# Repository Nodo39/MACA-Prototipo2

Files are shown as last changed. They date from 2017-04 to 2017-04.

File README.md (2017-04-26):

# MACA-Prototipo2

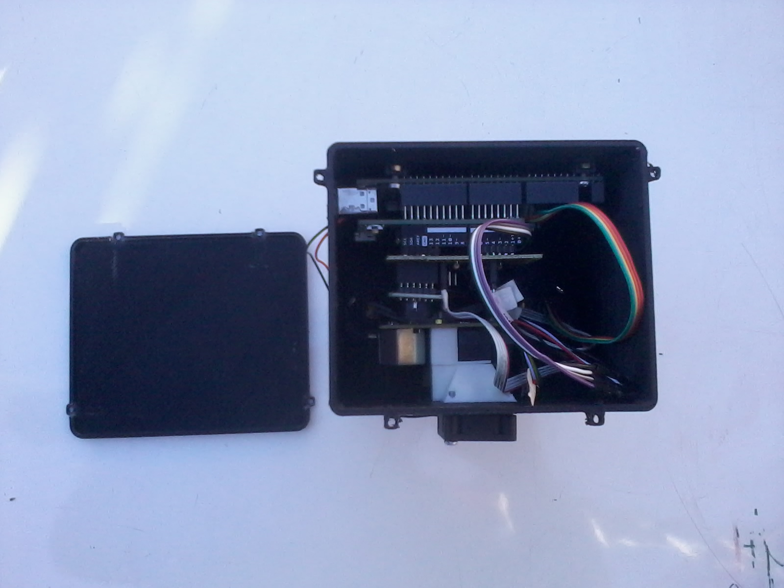
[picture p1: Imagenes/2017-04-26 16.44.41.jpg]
Vista superior

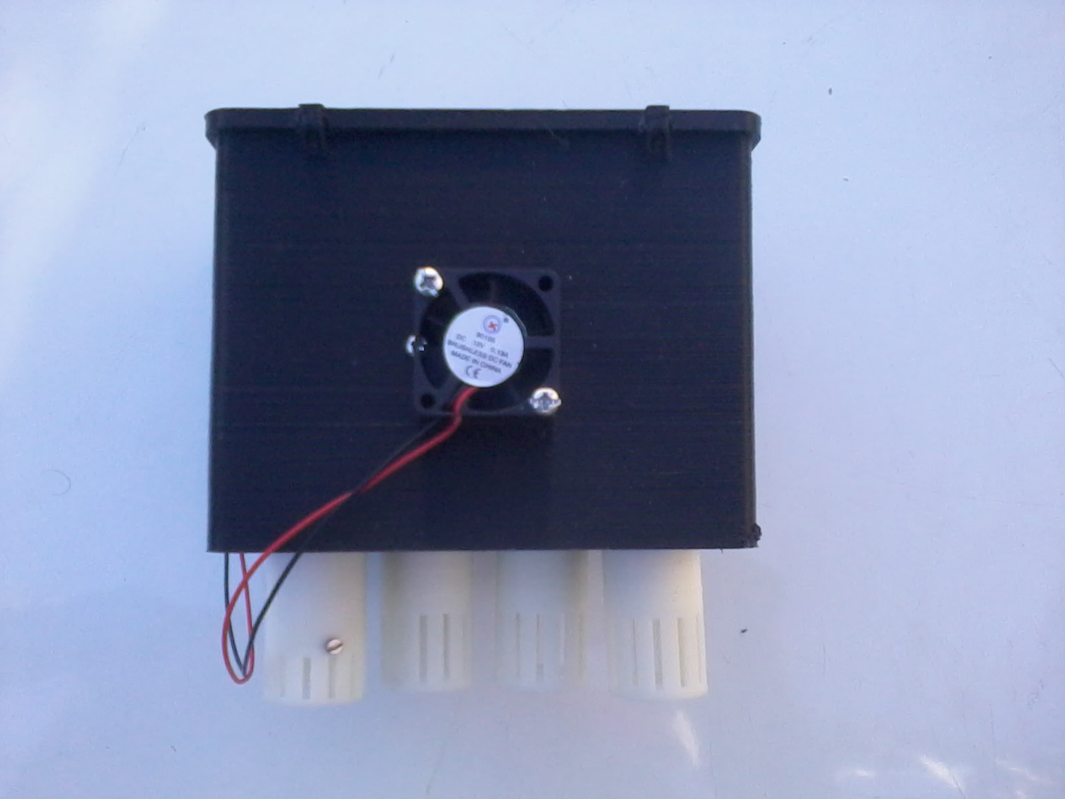
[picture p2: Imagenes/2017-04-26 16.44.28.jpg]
Vista frontal


MACA-Prototipo2 es una pequeña estación de monitoreo de la calidad del aire abierta y de bajo costo que combina un detector óptico de partìculas y sensores de oxidos metálicos (MICS-e2v) para los gases CO, NO2 and O3.
Esta estacíon es un remix y una adaptación de monitores abiertos previos (AQ Egg, Smartcitizen, Dustduino and Airbeam).
El prototipo está basado en un Arduino Mega 2560 y un shield WiFi.
En este repositorio estamos documentando el hardware y el sofware del equipo.
Para mayor información sobre el proyecto se puede consultar la wiki www.monitorabierto.wikidot.com o la [nota de investigaciòn en Public Lab](https://publiclab.org/notes/nanocastro/04-26-2017/maca-open-air-quality-monitor-project-in-latin-america)

MACA-Prototipo2 is an open, small and low cost air quality monitoring station that combines an optical particle detector (Shinyei) and metal oxide gas sensors for CO, NO2 and O3 (MICS-e2v).  
It’s a remix and adaptation of previous citizen air quality monitors (AQ Egg, Smartcitizen, Dustduino and Airbeam). 
This prototype is based on an Arduino Mega 2560 and a WiFi Shield.
In this respository we are documenting the hardware and software of this device.
For further information about the project you can check the wiki www.monitorabierto.wikidot.com or the [Research Note at Public Lab](https://publiclab.org/notes/nanocastro/04-26-2017/maca-open-air-quality-monitor-project-in-latin-america)

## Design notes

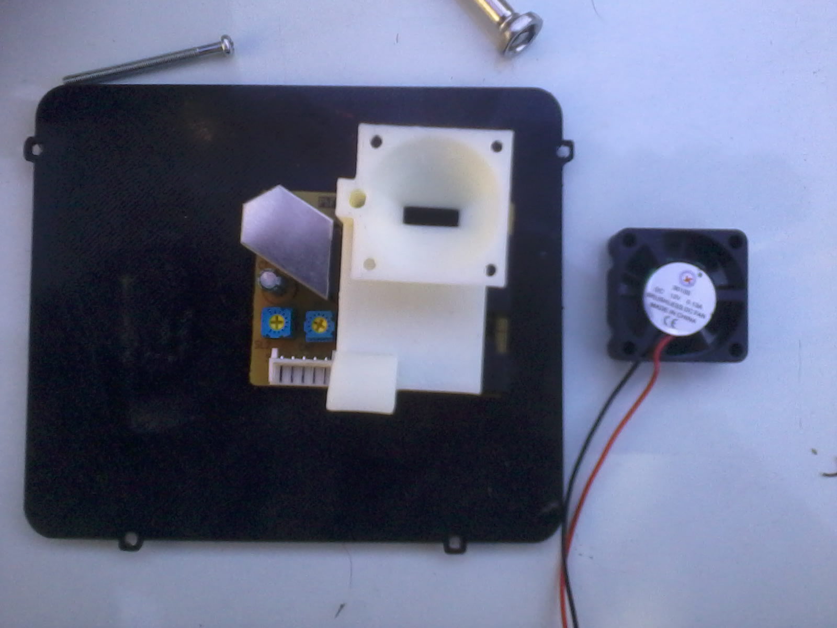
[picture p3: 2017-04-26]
Imagenes/2017-04-26 16.49.09.jpg

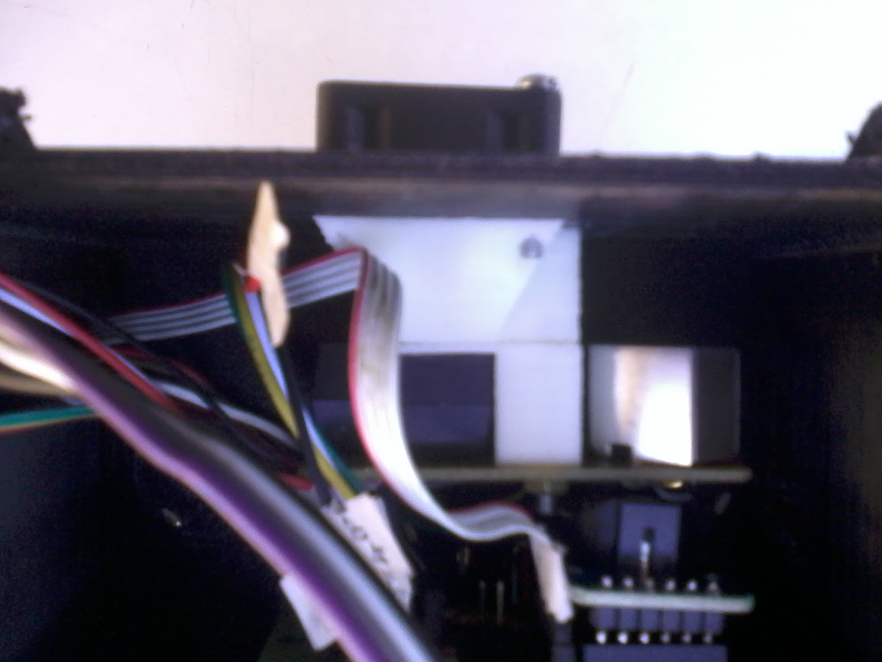
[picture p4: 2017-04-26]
Imagenes/2017-04-26 16.45.03.jpg

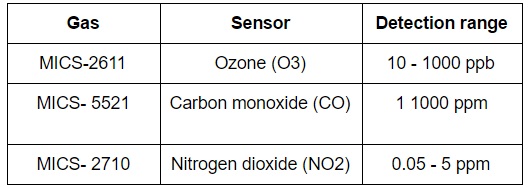
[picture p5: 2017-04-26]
Imagenes/gas sensors.jpg

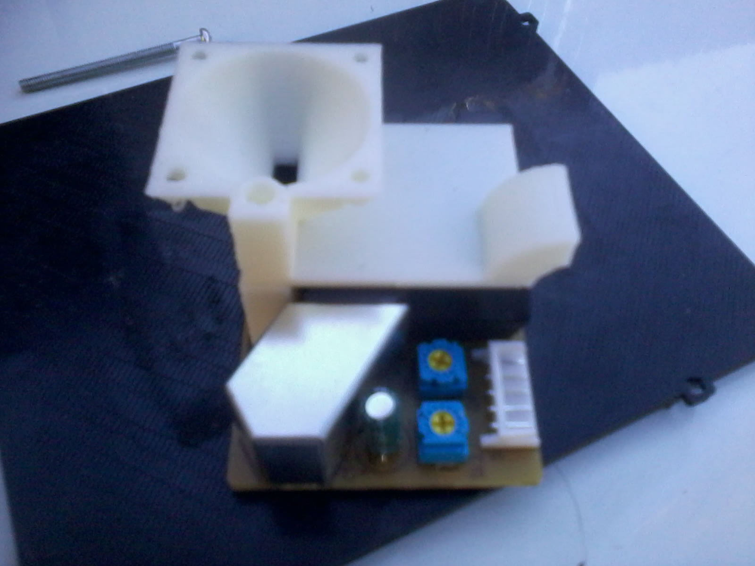
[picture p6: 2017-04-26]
Imagenes/2017-04-26 16.49.48.jpg

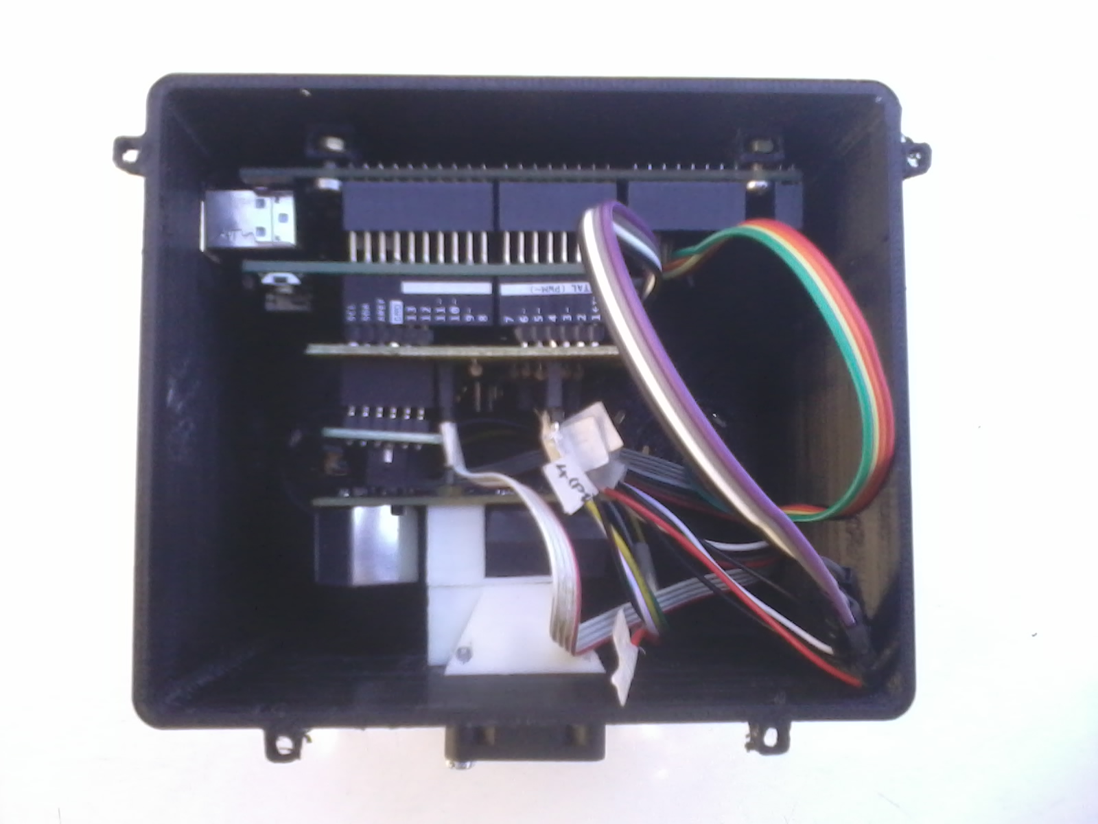
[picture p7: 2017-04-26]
Imagenes/2017-04-26 16.39.17.jpg

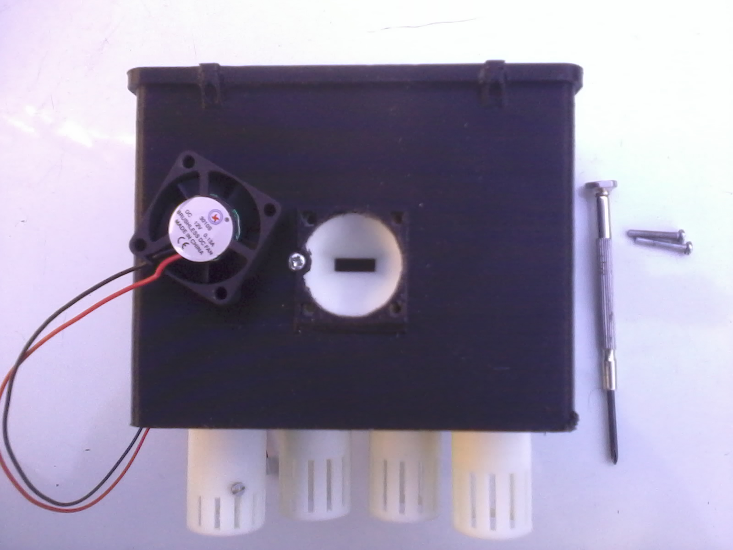
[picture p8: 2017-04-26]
Imagenes/2017-04-26 16.47.10.jpg

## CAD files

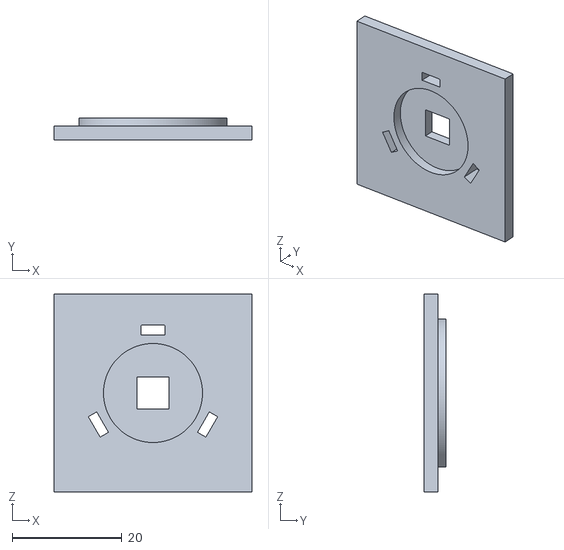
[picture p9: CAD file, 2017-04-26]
Hardware/Carcaza/acople base.stl
36.0 x 4.00 x 36.0

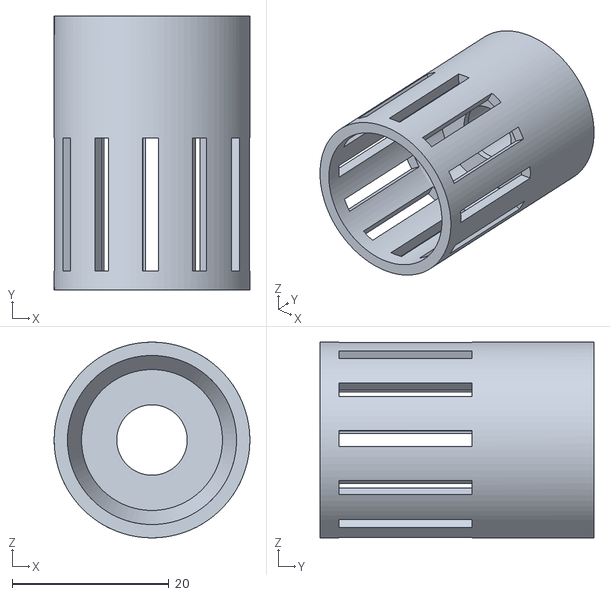
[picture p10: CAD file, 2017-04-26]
Hardware/Carcaza/Nueva carpeta/MICS holder v3.stl
25.0 x 35.0 x 25.0

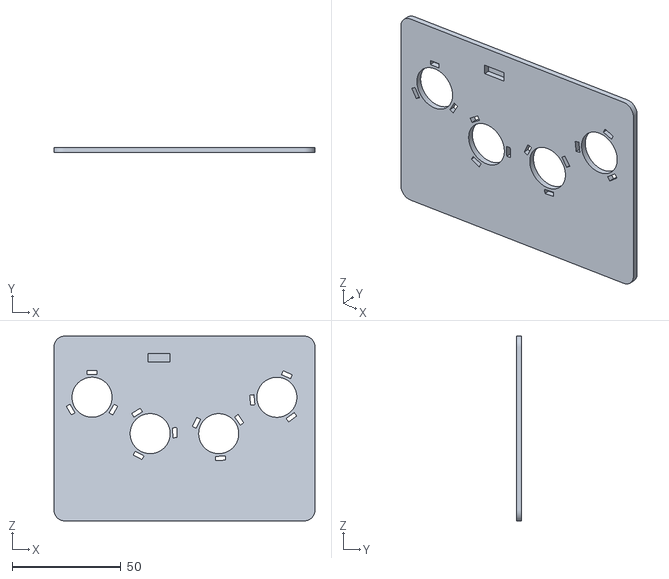
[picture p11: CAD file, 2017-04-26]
Hardware/Carcaza/Body2.stl
120.0 x 2.50 x 85.0

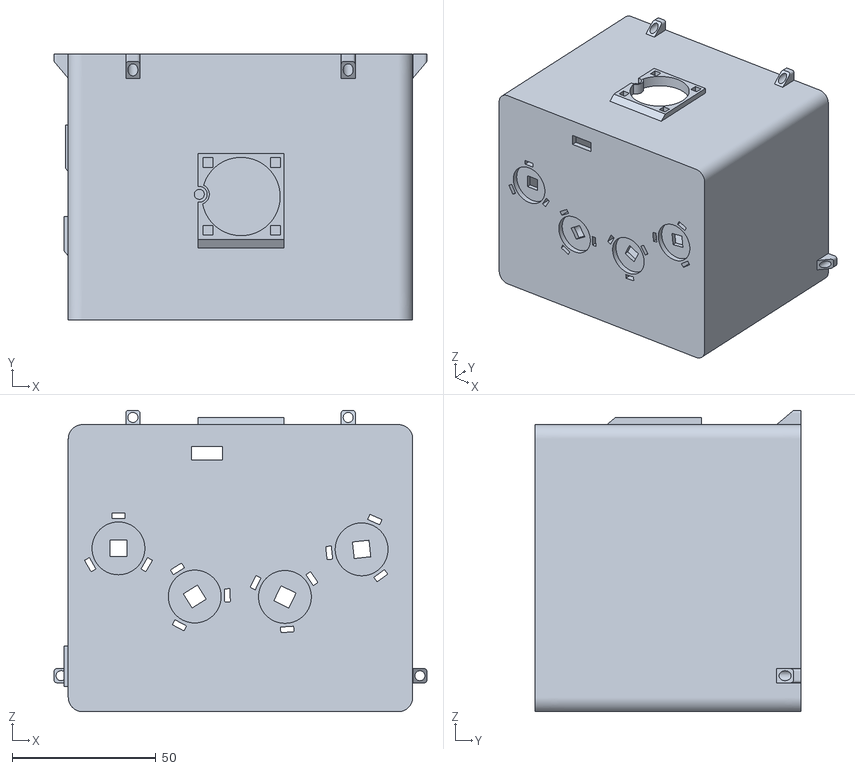
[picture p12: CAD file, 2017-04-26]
Hardware/Carcaza/Nueva carpeta/carcaza maca2 v1.stl
129.9 x 92.5 x 105.0

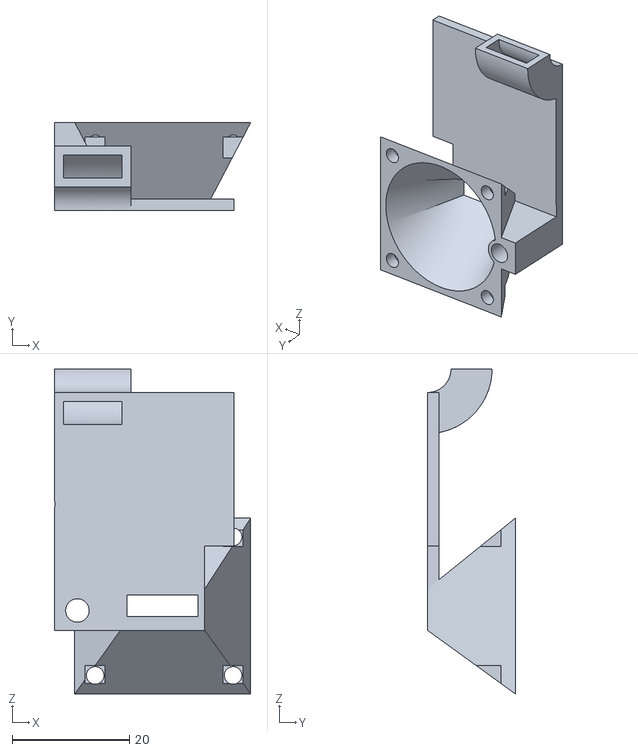
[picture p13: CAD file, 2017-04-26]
Hardware/Carcaza/Nueva carpeta/shinyei.stl
33.5 x 15.0 x 55.4

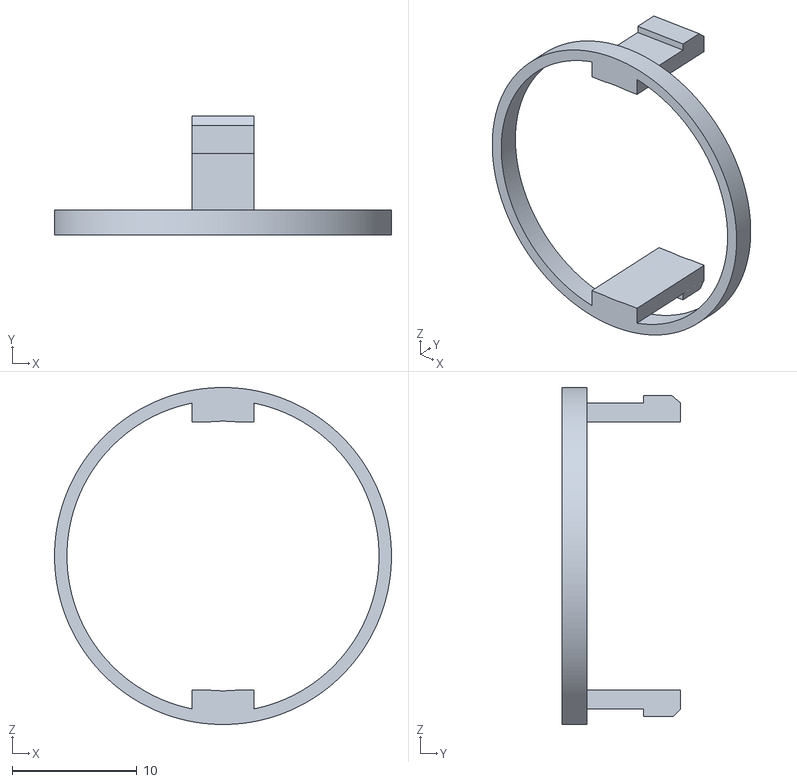
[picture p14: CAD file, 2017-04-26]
Hardware/Carcaza/ganchos sensor.stl
27.0 x 9.51 x 27.0

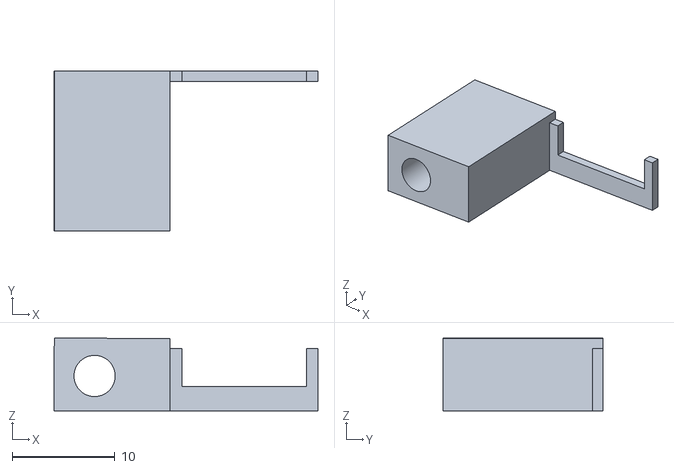
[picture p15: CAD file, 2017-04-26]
Hardware/Carcaza/Nueva carpeta/taco shinyei.stl
25.6 x 15.5 x 7.06

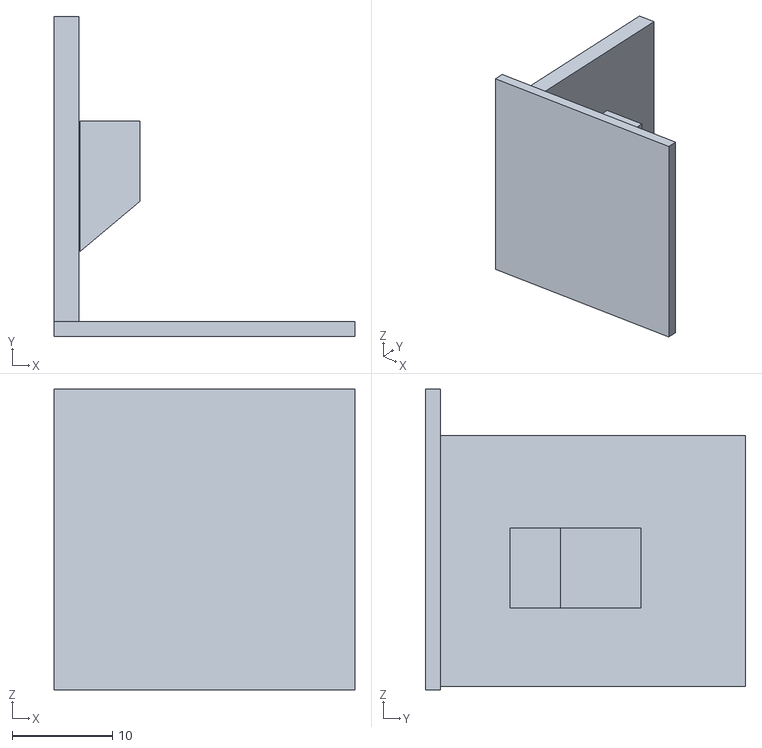
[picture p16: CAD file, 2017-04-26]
Hardware/Carcaza/anclaje pared.stl
30.0 x 31.9 x 30.0

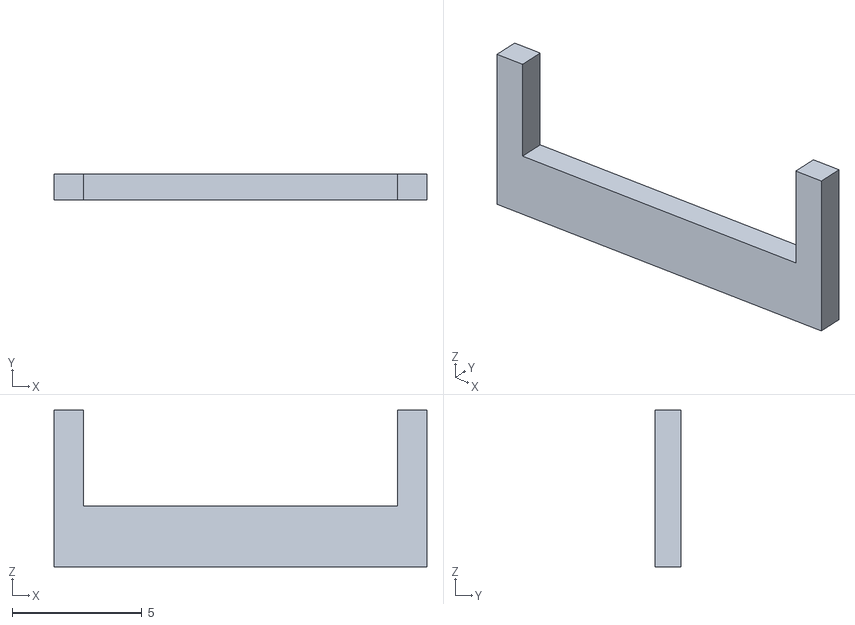
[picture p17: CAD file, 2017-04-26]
Hardware/Carcaza/Nueva carpeta/bordecito.stl
14.4 x 1.00 x 6.04

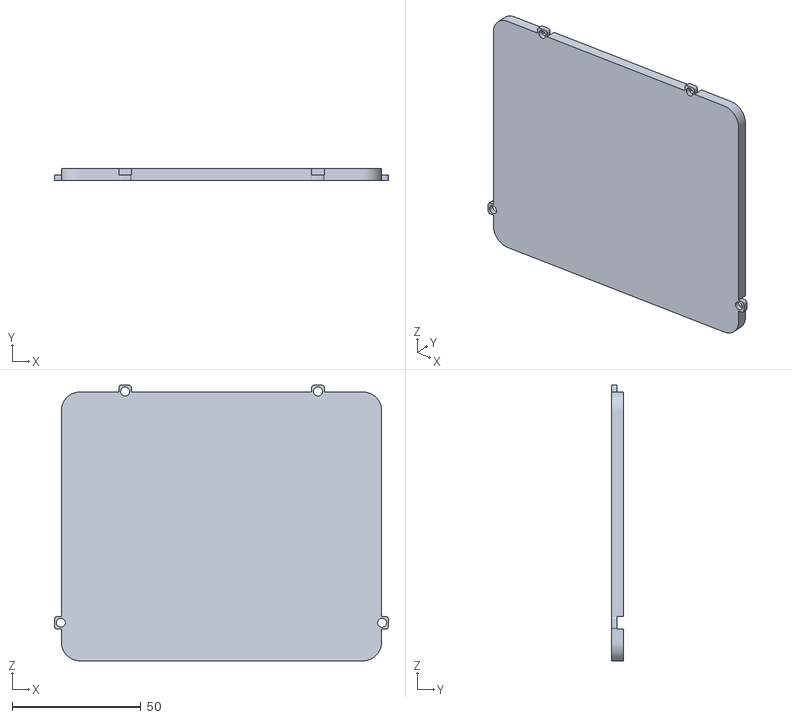
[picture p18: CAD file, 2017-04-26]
Hardware/Carcaza/Nueva carpeta/tapa.stl
129.9 x 4.50 x 107.3

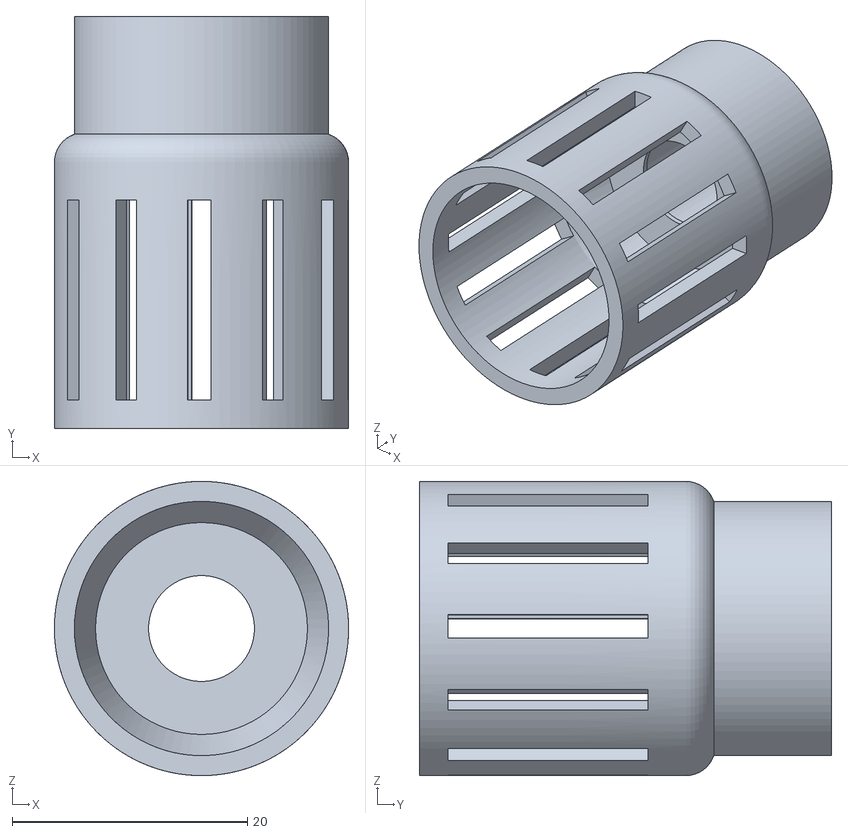
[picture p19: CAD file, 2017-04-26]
Hardware/Carcaza/sensor holder.stl
25.0 x 35.0 x 25.0

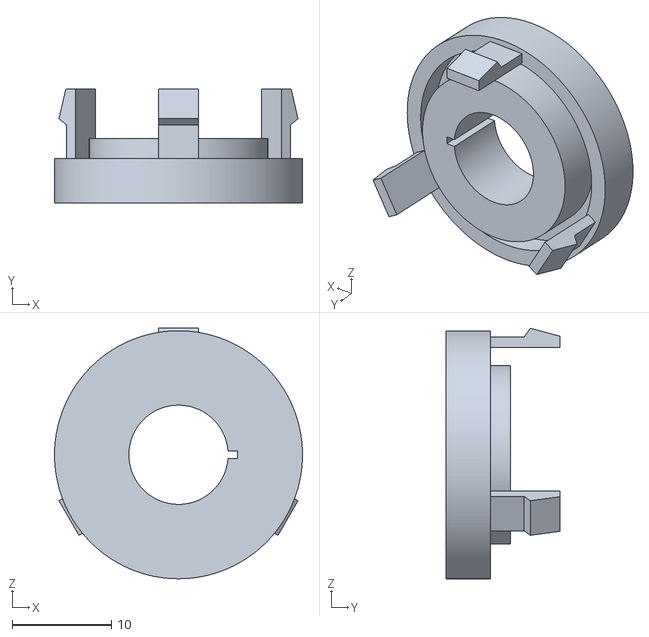
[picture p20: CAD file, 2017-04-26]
Hardware/Carcaza/gancho sensores.stl
25.0 x 11.5 x 25.3

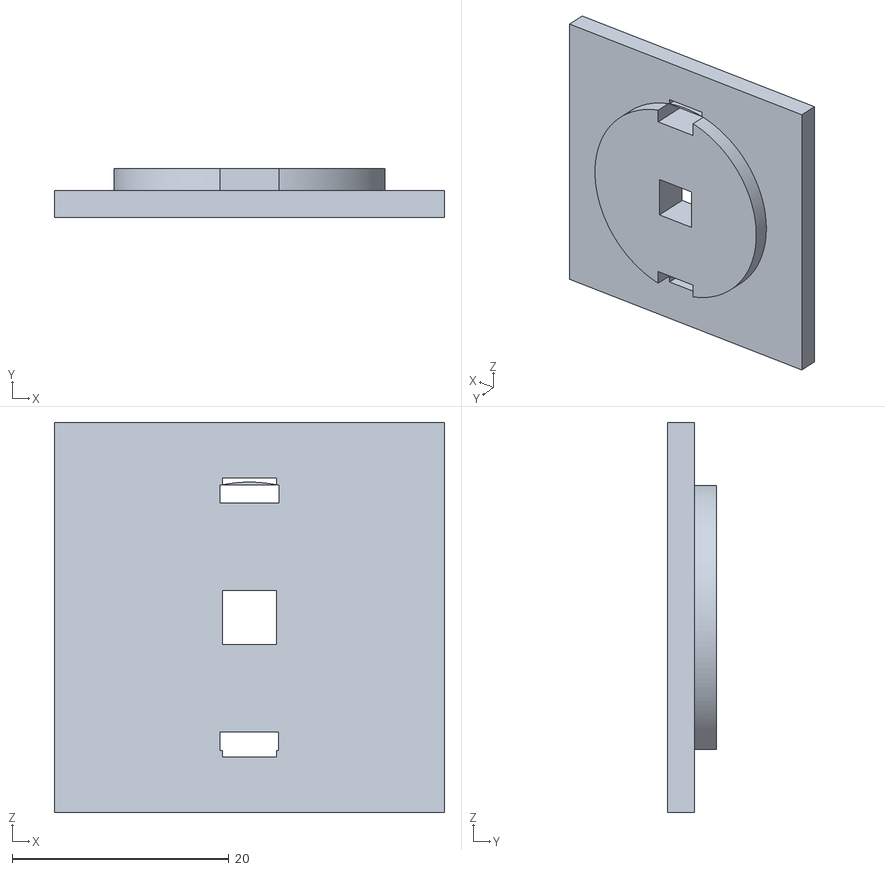
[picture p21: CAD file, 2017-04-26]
Hardware/Carcaza/union carcaza.stl
36.0 x 4.50 x 36.0

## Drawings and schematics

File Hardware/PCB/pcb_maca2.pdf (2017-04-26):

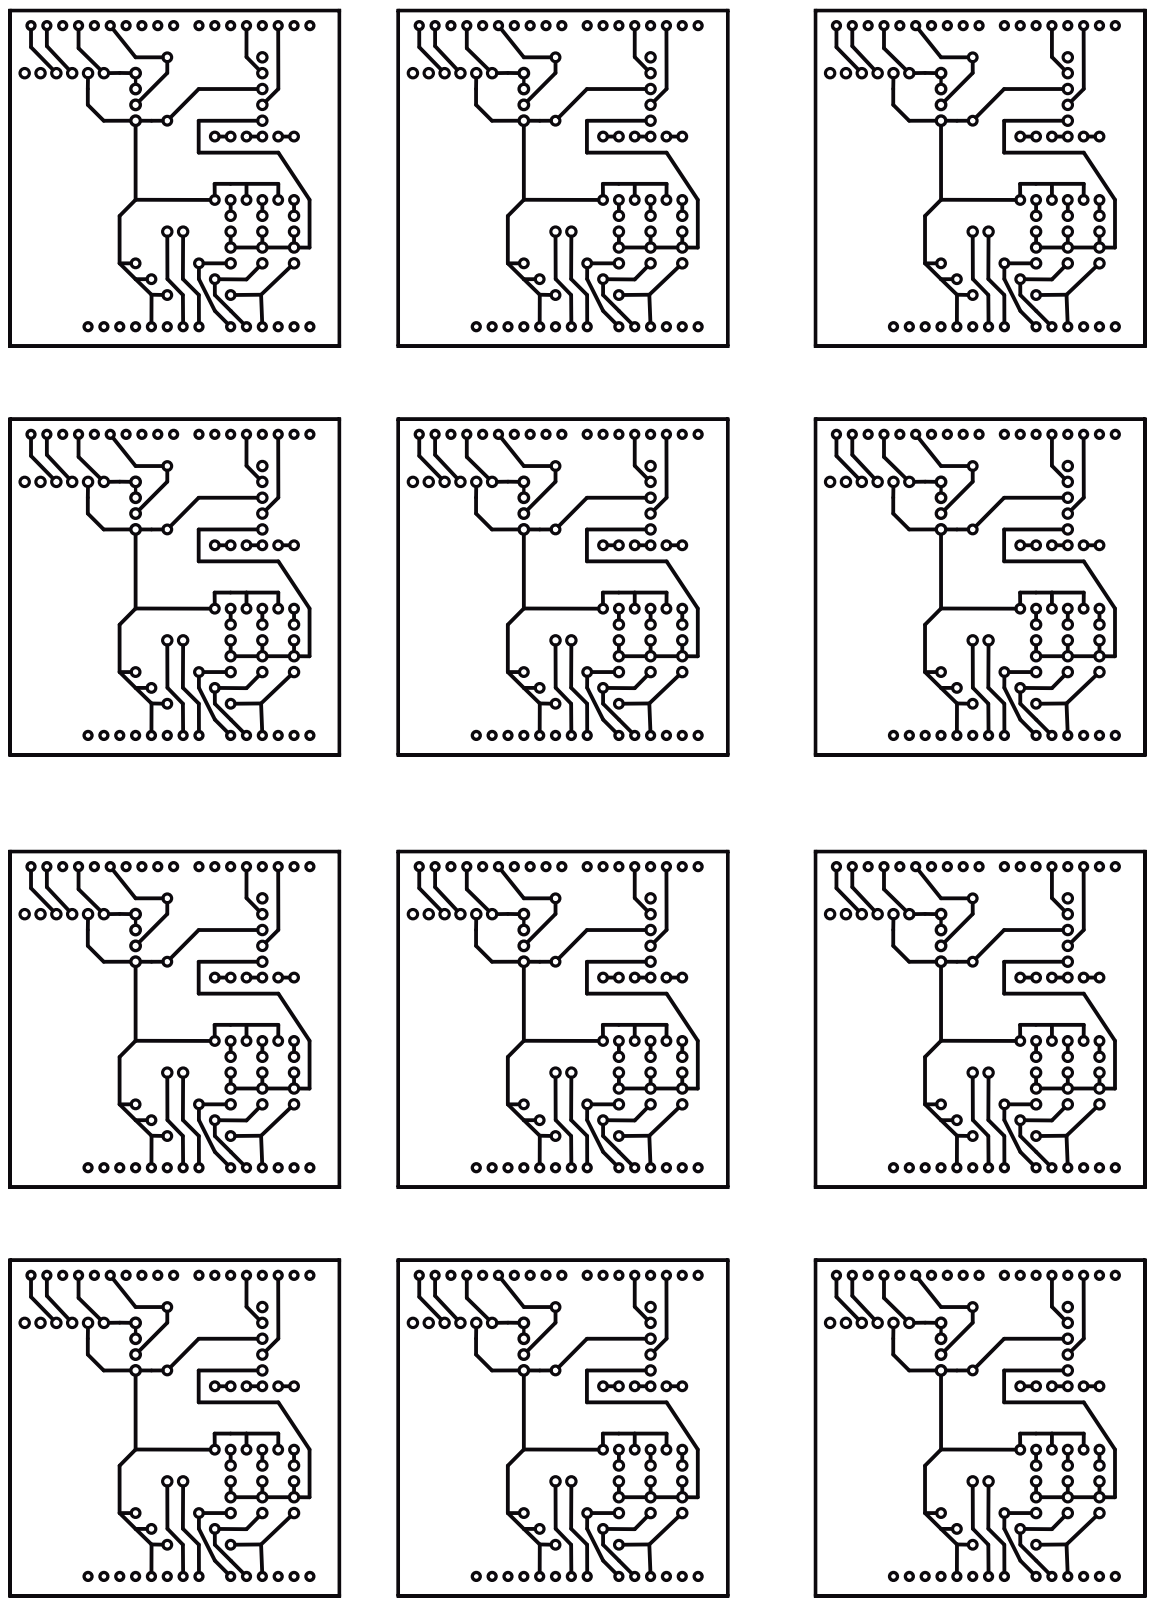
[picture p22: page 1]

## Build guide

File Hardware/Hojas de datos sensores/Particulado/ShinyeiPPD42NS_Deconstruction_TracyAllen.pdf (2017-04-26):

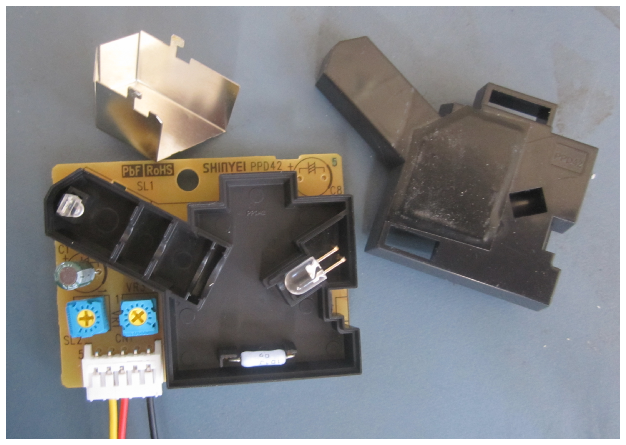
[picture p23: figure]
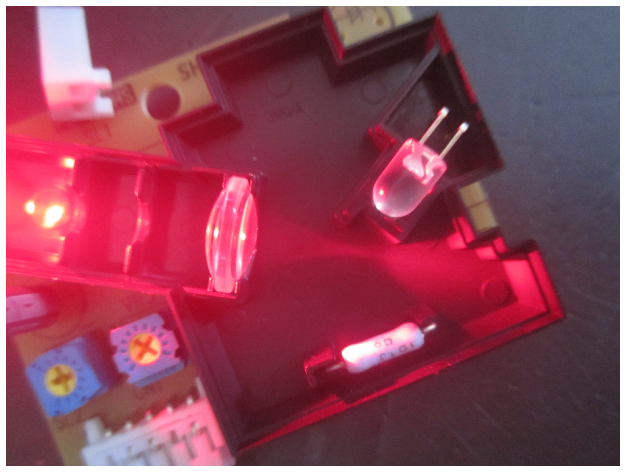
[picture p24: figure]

version 0.2, 30-May-2013 EME Systems, 2229 Fifth St., Berkeley CA 94710; (510) 848-5725; www.emesystems.com

De-construction of the Shinyei PPD42NS dust sensor.

I reverse engineered the circuit of the PPD42NS, two samples, date code 2/2002. Please refer to http://www.shinyei.co.jp/stc/optical/main_dust_e.html for the manufacturer’s description. See in particular at the bottom of that page an animation of the operating principle. My motivation for doing this is to understand better how the signal is processed internally. It is an clever device, but what is is really measuring? These observations should not be construed in any way as official word from Shinyei Technology. I make no warranty that my observations are correct. Caveat emptor!

The PPD42 entrains particles in a thermal plume provided by a 100Ω resistor, driven at 5V * 50mA = 0.25W. Particles convect up through an light beam provided by the infrared led, LED1. Light scattered by particles at a forward angle of about 45° is picked up by PIC1, photodiode. The light path is baffled to avoid stray light pickup, and a lens in front of the photodiode focuses into a detection region in the air flow and close to the LED light portal.

The shield can be unsoldered from the circuit board and removed,
and then a tab on the end releases the plastic top cover to reveal the interior.

In this photo a bright red LED is placed at the position of the photodiode, and artificial smoke is sprayed into the detection area in order to help to visualize the focal point of the lens. The cone of light can be clearly seen as it comes down to a focal point directly in front of the opening behind which sits the infrared LED. Turning it around, light from the IR LED, scattered by particles in that same area, would be focused in reverse up onto the photodiode.

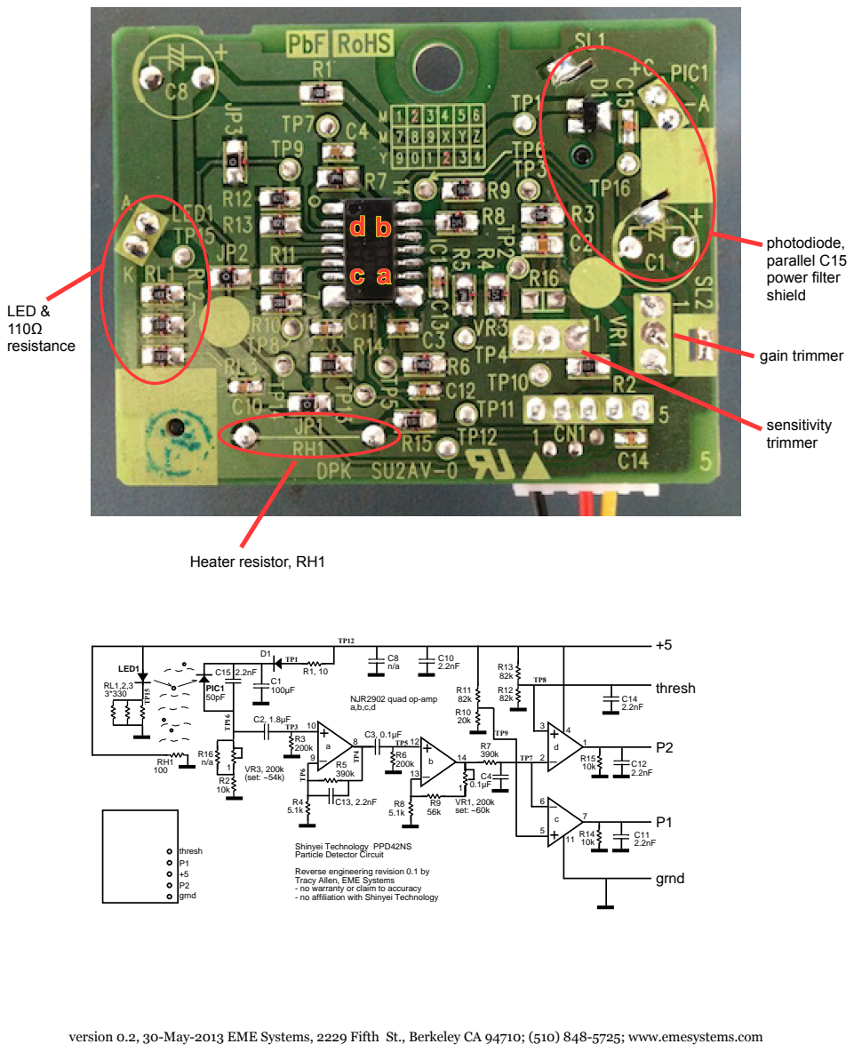
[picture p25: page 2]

Shinyei Technology PPD42NS
Particle Detector Circuit
Reverse engineering revision 0.1 by
Tracy Allen, EME Systems
- no warranty or claim to accuracy
- no affiliation with Shinyei Technology

Circuit description:

LED1 is in series with the 5V power supply and 110Ω of resistance, provided by 3*330Ω in parallel. The forward voltage of the diode was measured as 1.41V and the diode current was 33mA continuous. Note that the 5V power supply applied at the input connector should be well filtered, because fluctuations in power supply voltage will translate directly to fluctuations in light output from the LED, which will be indistinguishable from actual signal. In the devices tested, large supply filter capacitor C8 was not installed on the circuit board. C10 is a much smaller ceramic type.

Power to the photodiode is filtered by resistor R1, diode D1 and 100µF capacitor C1. I am assuming that PIC1 is a standard photodiode, rather than an integrated circuit. The name, PIC1, is puzzling. It has a forward voltage of 0.7V and its position in the circuit is consistent with it being a standard photodiode. The photodiode is reverse biased and is in series with a variable resistance comprised of R2, R16 and VR3. In the two that I tested, VR3 was set close to 50kΩ, and R16 was not installed on the circuit board.

Changes in light cause changes in current from the photodiode, and that develops changes in voltage across the combined resistance of R2,R16 and VR3. Adjusting VR3 to a higher resistance would increase the sensitivity. Capacitor C15 is in parallel with the photodiode and slows down and integrates the response on a time scale of a millisecond or so, and that time constant increases along with increases in the sensitivity adjustment.

Fluctuations in voltage are coupled through capacitor C2 and R3 into section a of the op-amp, which provides non-inverting low frequency voltage gain of x77.5. Low frequency here means everything above 0.5 Hz. C13 in the feedback path provides AC stability as it compensates for the input capacitor C15.

Fluctuations at the output of section a, are fed through capacitor C3 and R6 to section b of the op-amp, and this section provides adjustable DC gain from x12 to x50 with VR1 in combination with R8 and R9. In the two that I measured, VR1 was set at near 50kΩ, for a second stage gain of x22. The combination of C3 with R6 attenuates frequencies below 8Hz.

The output of section b feeds into a first order lowpass filter, R7 and C4. This section attenuates frequencies above 4Hz. The result of the combined high-pass C3:R6 and low-pass C4:R7 suggests that frequencies around 6 Hz are the least attenuated, and that pulses of a certain length and frequency are more apt to pass through to the output. This needs further analysis and experiment.

Sections c and d of the op-amp are set up as comparators to provide output pulses for the P1 and P2 outputs at the connector. Voltage divider R10 and R11 determine a threshold of 1.09V for P1. Similarly, R12 and R13 determine a threshold of 2.5V for P2, P1 and/or P2 will pulse low so long as the input voltage exceeds their respective thresholds. Note that any time the signal is high enough to activate P2, P1 will be active also. Applying an additional resistor or a voltage to the external threshold input could adjust the P2 threshold either up or down.

There are a number of test point TP1...TP16 scattered around the circuit board, and most of those are also marked on the schematic. Note that there are not official test points at the op-amp outputs at the corners of the 14-pin package, but the op-amp outputs are probably the best place for monitoring the circuit performance.

The op-amp is a generic NJM2902, which is essentially the same as the ubiquitous LM324. The circuit is very straightforward, as you can see, and does not involve tricks except for the clever heat pump and the nice optical chamber. There is no fancy large scale integrated circuit or microprocessor. Quite the contrary, and all the electronic parts are standard issue.

The PPD42 power drain is determined almost completely by the combination of the heater RH1, 50mA and LED1, 33mA.

Shinyei literature and other communications suggest that pulses at the P1 output correspond to 1µm particles, and pulses at the P2 output correspond to 2.5µm particles. That would seem to compare with the 1V and 2.5V thresholds set on the comparator inputs. There is presumably a calibration adjustment made to the sensitivity and gain trimmers in order to adjust the calibration to a standard maintained at Shinyei. Calibration would be necessary if only to account for variations in the components, and especially to adjust for the LED output and photodiode sensitivity. We should be skeptical though about any quantitative link to real particles in all their variety. The usual issues in interpretation of optical scattering apply here. Optical scattering properties of aerosols vary widely among different classes of particles. Also there is great variation within a heterogenous aerosol of one type or from one source dependent on a host of factors and over the course of time. The electronics suggest that the response is an average of clouds of many smaller or fewer larger particle that pass through the detection area in a sustained concentration large enough to push one or both of the outputs over their thresholds to give a pulse at the P1 or P2 outputs. It is not a particle counter in the sense of the Dylos, which does in fact count the pulses caused by individual particles, nor is it a photometer, that quantifies the an overall level of light scattering in a larger volume. It is a hybrid. The response of this sensor to specific aerosols will have to come from experiments and from colocations with standard instruments.

Possible to do on the hardware side:
-- measure temperature of the heater resistor above ambient.
-- measure resulting air velocity or volume movement of the convection current.
-- measure/analyze frequency and pulse response of the stages of the amplifier/comparator. Does the pulse response match up with the residence time of particles in the beam?
-- experiments, hacks. tap off the raw signal and process differently.
-- Replace the heater with a Murata piezo blower or Sunon miniature fan.

Tracy Allen
EME Systems LLC

The connector appears to be JST series EH. Specifically: crimp terminal: SEH-001T-P0.6 $0.03 each housing: EHR-5 $0.10 each
side entry header (as on the Shinyei): S5B-EH
top entry header: B5B-EH-A
These are in stock at major suppliers, Digikey, Future, Newark.

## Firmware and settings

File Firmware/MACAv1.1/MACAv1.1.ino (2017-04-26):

#include <WiFi.h>
#include <SPI.h>
#include <SD.h>

/* SD */
const int SDchipSelect = 4;
//#define DataloggerSD  //Enable data storage in SD card

/* WiFi */
char ssid[] = "nodo 39"; //  your network SSID (name)
char pass[] = "canelita32";    // your network password (use for WPA, or use as key for WEP)
int keyIndex = 0;            // your network key Index number (needed only for WEP)

int status = WL_IDLE_STATUS;
char server[] = "www.dweet.io";
//IPAddress server(192,168,0,1);

WiFiClient client;

// Dweet parameters
#define thing_name  "MACA"

/* RTC DS3231
 
 CONNECTIONS:
 DS3231 SDA --> SDA
 DS3231 SCL --> SCL
 DS3231 VCC --> 3.3v or 5v
 DS3231 GND --> GND
 */
#if defined(ESP8266)
#include <pgmspace.h>d
#else
#include <avr/pgmspace.h>
#endif

/* for software wire use below
#include <SoftwareWire.h>  // must be included here so that Arduino library object file references work
#include <RtcDS3231.h>

SoftwareWire myWire(SDA, SCL);
RtcDS3231<SoftwareWire> Rtc(myWire);
 for software wire use above */

/* for normal hardware wire use below */
#include <Wire.h> // must be included here so that Arduino library object file references work
#include <RtcDS3231.h>
RtcDS3231<TwoWire> Rtc(Wire);
/* for normal hardware wire use above */


/* DHT Sensor
 Connect pin 1 (on the left) of the sensor to +5V
 Connect pin 2 of the sensor to whatever your DHTPIN is
 Connect pin 4 (on the right) of the sensor to GROUND
 Connect a 10K resistor from pin 2 (data) to pin 1 (power) of the sensor
*/
#include <DHT.h>

#define DHTPIN 12

//#define DHTTYPE DHT11   // DHT 11
#define DHTTYPE DHT22   // DHT 22  (AM2302), AM2321
//#define DHTTYPE DHT21   // DHT 21 (AM2301)

DHT dht(DHTPIN, DHTTYPE);

float DHT_humidity;
float DHT_temperature;

/* Interface to Shinyei Model PPD42NS Particle Sensor
  JST Pin 1 (Black Wire) => Arduino GND
  JST Pin 3 (Red wire) => Arduino 5VDC
  JST Pin 4 (Yellow wire) => Arduino Digital Pin 8
*/

int Shinyei_P1 = 5;
int Shinyei_P2 = 3;
unsigned long duration;
unsigned long starttime;
unsigned long sampletime_ms = 15000;//sampe 30s ;
unsigned long lowpulseoccupancy = 0;
float ratio = 0;
float concentration = 0;

/*  MICS  */

int MiCS_2710 = A0;   //NO2 Sensor
int MICS_2611 = A1;   //O3  Sensor
int MICS_5521 = A2;   //CO  Sensor

int NO2_value = 0;
int O3_value  = 0;
int CO_value  = 0;

int NO2_out, O3_out, CO_out;

void setup() {
  Serial.begin(9600);

  #ifdef DataloggerSD 
  Serial.print("Initializing SD card...");

  // see if the card is present and can be initialized:
  if (!SD.begin(SDchipSelect)) {
    Serial.println("Card failed, or not present");
    // don't do anything more:
    return;
  }
  Serial.println("card initialized.");
  #endif

  WiFiSetup();
  
  RTCSetup();
  
  dht.begin();
  
  pinMode(Shinyei_P1,INPUT);
  pinMode(Shinyei_P2,INPUT);
  starttime = millis();//get the current time;
}

void loop() {
  
  String dataString = "";
  
  // Wait a few seconds between measurements.
  delay(2000);

  //-------------RTC-------------------
  if (!Rtc.IsDateTimeValid()) 
    {
        // Common Cuases:
        //    1) the battery on the device is low or even missing and the power line was disconnected
        Serial.println("RTC lost confidence in the DateTime!");
    }

    RtcDateTime now = Rtc.GetDateTime();
    printDateTime(now);
    Serial.println();

    RtcTemperature temp = Rtc.GetTemperature();
//    Serial.print("RTC Temp: ");
//    Serial.print(temp.AsFloat());
//    Serial.println("C");
  
  //-------------DHT SENSOR--------------
  // Reading temperature or humidity takes about 250 milliseconds!
  // Sensor readings may also be up to 2 seconds 'old' (its a very slow sensor)
  DHT_humidity = dht.readHumidity();
  // Read temperature as Celsius (the default)
  DHT_temperature = dht.readTemperature();

  // Check if any reads failed and exit early (to try again).
  if (isnan(DHT_humidity) || isnan(DHT_temperature)) {
    Serial.println("Failed to read from DHT sensor!");
    return;
  }
  
  dataString += "DHT - ";
  dataString += "Humidity: ";
  dataString += String(DHT_humidity);
  dataString += " %";
  dataString += " , ";
  dataString += "Temperature: ";
  dataString += String(DHT_temperature);
  dataString += " C";
  dataString += "\n";
  
//  Serial.print("Humidity: ");
//  Serial.print(DHT_humidity);
//  Serial.print(" %\t");
//  Serial.print("Temperature: ");
//  Serial.print(DHT_temperature);
//  Serial.println(" C ");

  //------------SHINYEI--------------
  duration = pulseIn(Shinyei_P1, LOW);
  lowpulseoccupancy = lowpulseoccupancy+duration;
  if ((millis() -starttime) > sampletime_ms)//if the sampel time == 30s
  {
    ratio = lowpulseoccupancy/(sampletime_ms*10.0); // Integer percentage 0=>100
    concentration = 1.1*pow(ratio,3) -3.8*pow(ratio,2)+520*ratio+0.62; // using spec sheet curve
    dataString += "Shinyei: concentration = ";
    dataString += String(concentration);
    dataString += " pcs/0.01cf";
    dataString += "\n";
//    Serial.print("concentration = ");
//    Serial.print(concentration);
//    Serial.println(" pcs/0.01cf");
//    Serial.println("\n");
    lowpulseoccupancy = 0;
    starttime = millis();
  }
  
  //------------MiCS------------

  NO2_value = analogRead(MiCS_2710);
  O3_value  = analogRead(MICS_2611);
  CO_value  = analogRead(MICS_5521);

  NO2_out = map(NO2_value, 0, 1023, 0, 1023);
  O3_out  = map(O3_value, 0, 1023, 0, 1023);
  CO_out  = map(CO_value, 0, 1023, 0, 1023);

  dataString += "NO2: ";
  dataString += String(NO2_out);
  dataString += " []";
  dataString += "\n";
  dataString += "O3: ";
  dataString += String(O3_out);
  dataString += " []";
  dataString += "\n";
  dataString += "CO: ";
  dataString += String(CO_out);
  dataString += " []";
  dataString += "\n";
  
  //------------WiFi------------

  SendDataToServer ();
  
  // if there are incoming bytes available
  // from the server, read them and print them:
  while (client.available()) {
    char c = client.read();
    Serial.write(c);
  }
  
  // if the server's disconnected, stop the client:
  if (!client.connected()) {
    Serial.println("disconnected from server.");
    client.stop();
  }
    
  //---------DATALOGGER---------
  #ifdef DataloggerSD
    // open the file. note that only one file can be open at a time,
    // so you have to close this one before opening another.
    File dataFile = SD.open("datalog2.txt", FILE_WRITE);
  
    // if the file is available, write to it:
    if (dataFile) {
      dataFile.println(dataString);
      dataFile.close();
      // print to the serial port too:
      Serial.println(dataString);
    }
    // if the file isn't open, pop up an error:
    else {
      Serial.println("error opening datalog2.txt");
    }
  #endif
   Serial.println(dataString);
   Serial.println();
}



void WiFiSetup()
{
  // check for the presence of the shield:
  if (WiFi.status() == WL_NO_SHIELD) {
    Serial.println("WiFi shield not present");
    // don't continue:
    while (true);
  }

  String fv = WiFi.firmwareVersion();
  //Serial.println(fv);
  if (fv != "1.1.0") {
    Serial.println("Please upgrade the firmware");
  }

  // attempt to connect to Wifi network:
  while (status != WL_CONNECTED) {
    Serial.print("Attempting to connect to SSID: ");
    Serial.println(ssid);
    // Connect to WPA/WPA2 network. Change this line if using open or WEP network:
    status = WiFi.begin(ssid, pass);

    // wait 10 seconds for connection:
    delay(10000);
  }
  Serial.println("Connected to wifi");
  printWifiStatus();

  Serial.println("\nStarting connection to server...");
  // if you get a connection, report back via serial:
  if (client.connect(server, 80)) {
    Serial.println("connected to server");
    
    // Make a HTTP request:
    client.print("GET /dweet/for//MACA1?");
    client.print("Temperature=");
    client.print(DHT_temperature);
    client.print("C");
    client.print("&Humidity=");
    client.print(DHT_humidity);
    client.print("%");
    client.print("&NO2=");
    client.print(NO2_out);
    client.print("&O3=");
    client.print(O3_out);
    client.print("&CO=");
    client.print(CO_out);
    client.println("");
    
    client.println("Host: dweet.io");
    client.println("Connection: close");
    client.println();
  }
}

void printWifiStatus() {
  // print the SSID of the network you're attached to:
  Serial.print("SSID: ");
  Serial.println(WiFi.SSID());

  // print your WiFi shield's IP address:
  IPAddress ip = WiFi.localIP();
  Serial.print("IP Address: ");
  Serial.println(ip);

  // print the received signal strength:
  long rssi = WiFi.RSSI();
  Serial.print("signal strength (RSSI):");
  Serial.print(rssi);
  Serial.println(" dBm");
}

void SendDataToServer ()
{
   if (client.connected()) {
    Serial.print(F("Sending request... "));
    
    client.print(F("GET /dweet/for/"));
    client.print(thing_name);
    client.print(F("?temperature="));
    client.print(DHT_temperature);
    client.print(F("&humidity="));
    client.print(DHT_humidity);
    client.println(F(" HTTP/1.1"));
    
    client.println(F("Host: dweet.io"));
    client.println(F("Connection: close"));
    client.println(F(""));
    
    Serial.println(F("done."));
  } else {
    Serial.println(F("Connection failed"));    
    return;
  }
}

#define countof(a) (sizeof(a) / sizeof(a[0]))

void RTCSetup()
{
  Serial.print("compiled: ");
  Serial.print(__DATE__);
  Serial.println(__TIME__);

  //--------RTC SETUP ------------
  Rtc.Begin();

  // if you are using ESP-01 then uncomment the line below to reset the pins to
  // the available pins for SDA, SCL
  // Wire.begin(0, 2); // due to limited pins, use pin 0 and 2 for SDA, SCL

  RtcDateTime compiled = RtcDateTime(__DATE__, __TIME__);
  printDateTime(compiled);
  Serial.println();

  if (!Rtc.IsDateTimeValid()) 
  {
      // Common Cuases:
      //    1) first time you ran and the device wasn't running yet
      //    2) the battery on the device is low or even missing

      Serial.println("RTC lost confidence in the DateTime!");

      // following line sets the RTC to the date & time this sketch was compiled
      // it will also reset the valid flag internally unless the Rtc device is
      // having an issue

      Rtc.SetDateTime(compiled);
  }

  if (!Rtc.GetIsRunning())
  {
      Serial.println("RTC was not actively running, starting now");
      Rtc.SetIsRunning(true);
  }

  RtcDateTime now = Rtc.GetDateTime();
  if (now < compiled) 
  {
      Serial.println("RTC is older than compile time!  (Updating DateTime)");
      Rtc.SetDateTime(compiled);
  }
  else if (now > compiled) 
  {
      Serial.println("RTC is newer than compile time. (this is expected)");
  }
  else if (now == compiled) 
  {
      Serial.println("RTC is the same as compile time! (not expected but all is fine)");
  }

  // never assume the Rtc was last configured by you, so
  // just clear them to your needed state
  Rtc.Enable32kHzPin(false);
  Rtc.SetSquareWavePin(DS3231SquareWavePin_ModeNone); 
}

void printDateTime(const RtcDateTime& dt)
{
    char datestring[20];

    snprintf_P(datestring, 
            countof(datestring),
            PSTR("%02u/%02u/%04u %02u:%02u:%02u"),
            dt.Month(),
            dt.Day(),
            dt.Year(),
            dt.Hour(),
            dt.Minute(),
            dt.Second() );
    Serial.print(datestring);
}
